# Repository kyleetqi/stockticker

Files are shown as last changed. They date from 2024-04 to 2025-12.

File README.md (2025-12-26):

# Introduction
* This project was inspired by Michael Klements' [ESP32 Stock Ticker](https://www.the-diy-life.com/bitcoin-ticker-using-an-esp32-and-oled-display/) and [this Reddit post.](https://www.reddit.com/r/wallstreetbets/comments/lfkprt/finished_my_diy_project_just_in_time_for_gme_to/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)
* These files are for **PERSONAL USE** only. Please contact me if you wish to use these files commercially.
* Please read through all documentation before starting this project.
* [Demo Video](https://youtu.be/1aN1ztKmoxc)

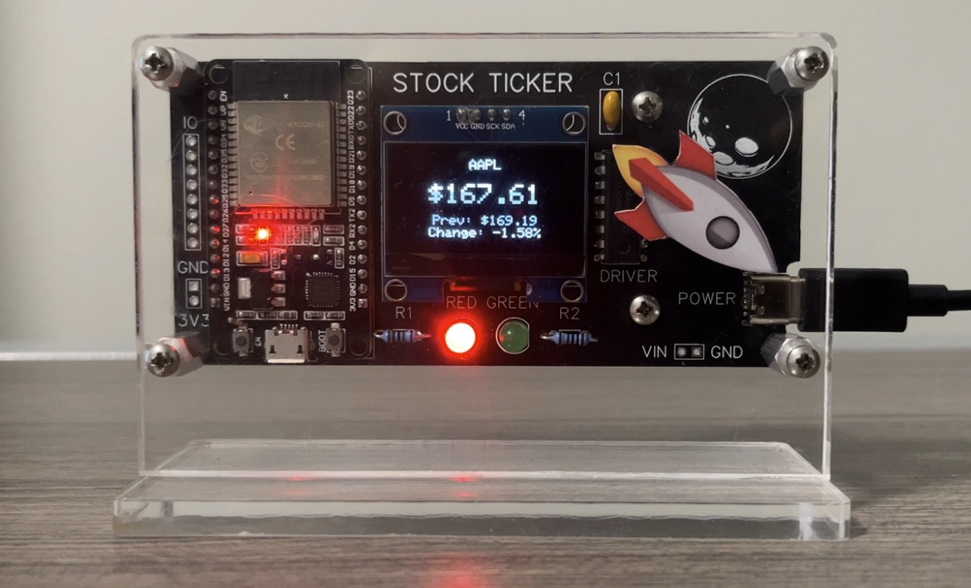
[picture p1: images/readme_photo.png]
Stock ticker display mounted on a circuit board.


# Known Issues and Limitations
* Although finnhub.io claims to provide live stock information, the API response may not be up to date at all times.
* Please contact me if you find any issues with the repository. :)
* There are some known issues with the USB-C port. 
  * Please check that your cable and brick can successfully supply power to the board. I had issues with Apple products.
  * The USB-C port is located a bit far into the board. Because of this, it may be necessary to file down the side of the PCB to plug in the cable. **PLEASE THOROUGHLY VERIFY IF THIS IS NECESSARY FOR YOU.**
* Because this project uses a stepper without absolute encoding, the ticker has no memory of the motor position between power ons. The pointer position needs to be reset before each power on.
  
# Bill of Materials
* I sourced all my parts from Sayal, (a hobbyist electronics store), but feel free to source from wherever you'd like.
* Use your judgement when substituting parts ensuring compatibility with the code and PCB. Modify the code and gerber as necessary.

### Required Items
Qty | Item Description | Notes |
--- | --- | --- |
1 | [DOIT ESP32 DEVKIT V1](https://shop.sayal.com/products/1815-ha1?_pos=1&_sid=3067e8a6e&_ss=r)  |  |
1 | [ULN2003 IC](https://shop.sayal.com/products/1814-lc1?_pos=3&_sid=53d498842&_ss=r) | The IC and motor come as a set if ordering from Sayal. | 
1 | [28BYJ-48 Stepper Motor](https://shop.sayal.com/products/1814-lc1?_pos=3&_sid=53d498842&_ss=r) | See note above. |
1 | [SH1106 OLED Display](https://shop.sayal.com/products/1814-fa1?_pos=1&_sid=ff4679778&_ss=r) | Some displays swap the position of VCC and GND. Verify the display pinout is compatible with PCB.|
1 | Red LED |  |
1 | Green LED |  |
1 | 0.1 uF capacitor | 1 uF should be fine as well. |
2 | Resistor | Choose between 360Ω and 1k Ω to control LED brightness. |
1 | [6-pin USB-C jack](https://shop.sayal.com/products/amtc-1154?_pos=3&_sid=0e93b7e13&_ss=r) |  |
1 | Pointer | 3D print using `pointer-rocket.stp`. If designing your own pointer, ensure the cylinder's inner diameter is 5mm. |
2 | #4-40 x 1/4" Screw | Used to mount the motor. M3 hardware is a suitable substitute. |
2 | #4-40 Nut | Used to mount the motor. M3 hardware is a suitable substitute. |
As Req. | Insulating tape | Electrical tape, etc. |

### Optional Items
* The following items are used to mount the PCB to the acrylic stand I designed. If you decide to mount the PCB another way, choose your hardware accordingly.

Qty | Item Description | Notes |
--- | --- | --- |
1 | Acrylic Stand | Laser cut using `pcb-cover.dwg` |
4 | [#4-40 x 12.7mm Standoff](https://shop.sayal.com/products/krc-164-2?_pos=8&_sid=6d0b828ae&_ss=r)| M3 hardware is a suitable substitute. |
4 | #4-40 x 1/4" Screw | M3 hardware is a suitable substitute. |
4 | #4-40 x 3/8" Screw | M3 hardware is a suitable substitute. |

# PCB
* If you plan on ordering PCBs using the provided gerber file, I recommend specifying where the manufacturer prints their PCB ID#. Make sure to select the `specify ID location` option before checking out!
  * If you are ordering from JLCPCB, you do not need to edit the gerber file.
  * If you are ordering from PCBWay, edit `JLCJLCJLCJLC` to `WayWayWay`.
  * If you are ordering from another manufacturer, follow their instructions accordingly.

# Software
* Ensure you have the Arduino IDE installed.
  * You may also use the PlatformIO extension on VSCode at your own discretion. 
* If this is your first time flashing your ESP32, I recommend referencing a [comprehensive setup guide.](https://randomnerdtutorials.com/installing-the-esp32-board-in-arduino-ide-windows-instructions/)
* Connect your ESP32 to your computer and open up `stockticker-public.ino` using the Arduino IDE.
* Ensure you have selected `DOIT ESP32 DEVKIT V1` as your board, and the correct serial port for communication.
  * At this stage, you may want to test if you have successfully established a connection with your ESP32. Try running an example such as the one at `File` > `Examples` > `Wifi` > `WiFiScan`
  * When trying to upload code onto your ESP32, you may encounter the error: `Failed to establish serial connection.` To resolve this, open the **serial monitor** and hold the `BOOT` and then `EN`(RESET) buttons down on your ESP32. You should see a response in the monitor at which point the code should be able to upload successfully.
* Install the following libraries required to compile the code:

Library Name | Author |
--- | --- |
Adafruit BusIO | Adafruit |
Adafruit GFX Library | Adafruit |
Adafruit SH110X | Adafruit | 
ArduinoJson | Benoit Blanchon |

* To fetch real, live stock market information, obtain a free API key from [finnhub.io.](https://finnhub.io/)
* Change the network and API parameters at the top of the code as necessary such as `symbol`, `key`, `ssid`, `pass`, etc.
* Modify the `updateTime` variable to set how frequently the device updates price information.
* Modify the `motorResponse` variable to control how sensitive the pointer is to stock changes.
* Verify and upload the code onto the ESP32.

# Soldering and Installation
* Before soldering components onto the board, use the schematic to wire and test the system on a breadboard to ensure everything is working.
* Verify that your cable can successfully plug into the USB-C port before soldering it into the board. See the `Known Issues and Limitations` section.
* Extract the ULN2003 IC from the driver board that comes with the motor and solder it directly onto the front of the PCB **before** installing the motor.
* [Insulate](./images/insulation-example.JPG) the ULN2003 pins on the backside of the PCB using the insulating tape.
* Mount the motor to the back of the PCB using hardware so that the shaft protrudes through the 10mm hole in the PCB towards the front.
* Cut the motor wires to length and solder them onto the back of the PCB making sure to pay attention to which color corresponds to which hole.
* Turn the PCB back over to the front and insulate the solder from the motor connections. Afterwards, solder on the OLED display.
* Solder all other components.
* Install the pointer onto the shaft of the motor.
* Mount the device using the fastener holes on the PCB.

# Operation
* Plug and play. Use power supply that is rated at 5V and can supply at least 2A. A phone charging brick should be sufficient. **DO NOT USE MORE THAN ONE POWER SOURCE AT THE SAME TIME.**
* Manually level the pointer to horizontal before powering the device since the motor does not have absolute encoding. The motor doesn’t remember its position between power ons.
* If the ESP32 is unable to establish a connection to the internet or API, it will automatically enter demo mode and generate random data.

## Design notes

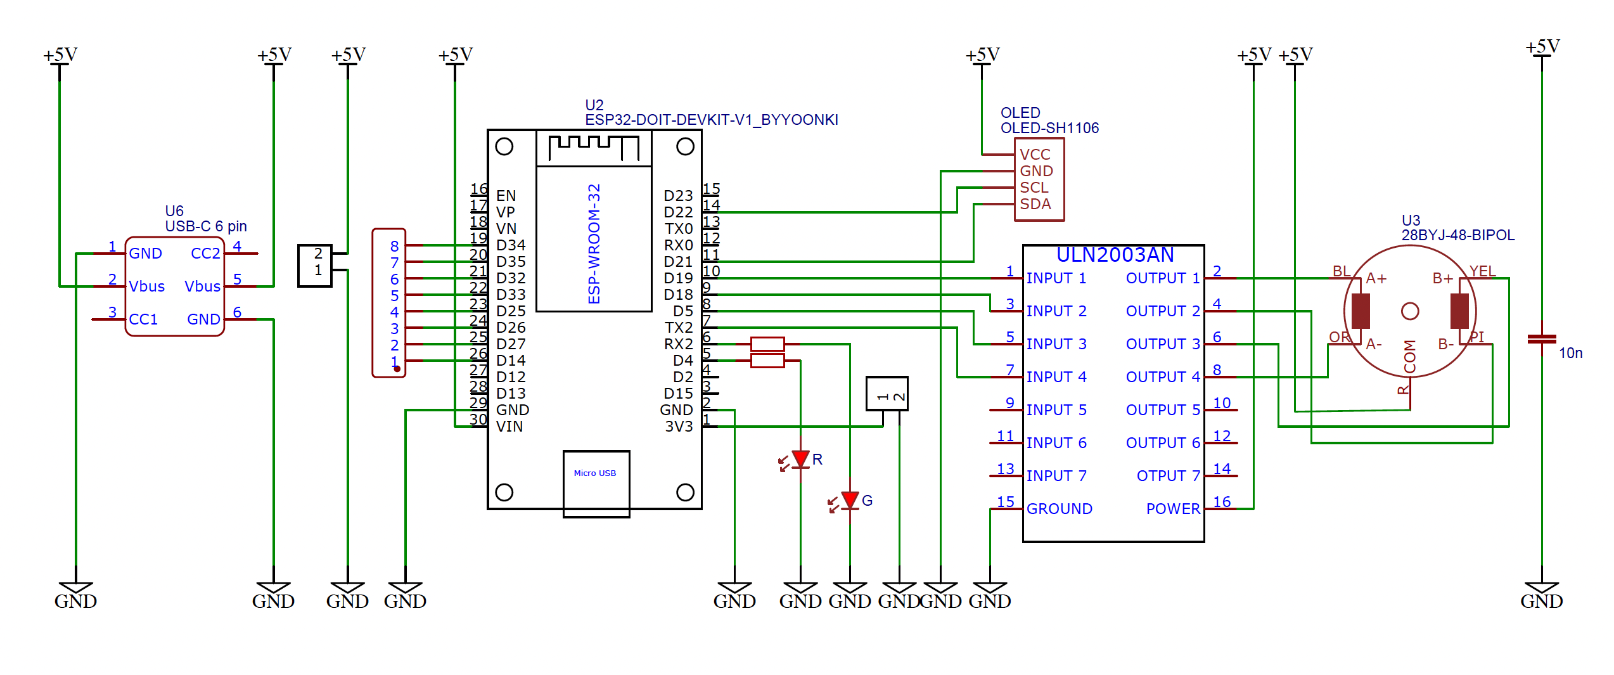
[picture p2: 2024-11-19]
schematic-11.18.24.png

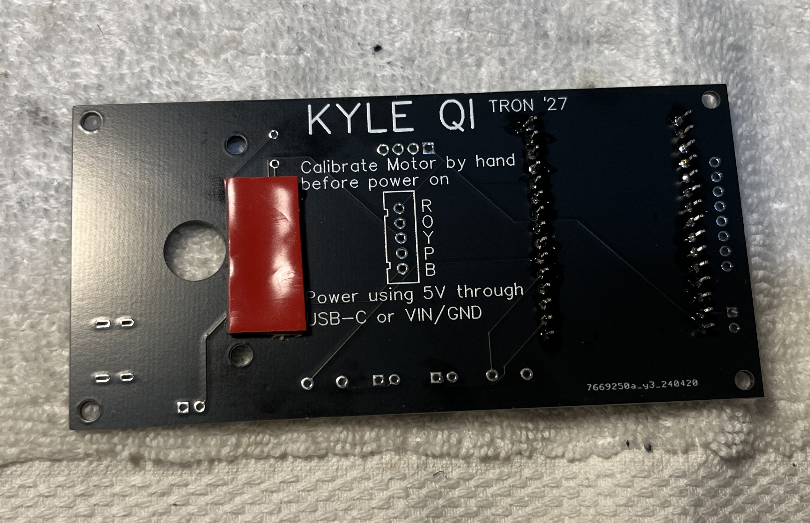
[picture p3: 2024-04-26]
images/insulation-example.JPG

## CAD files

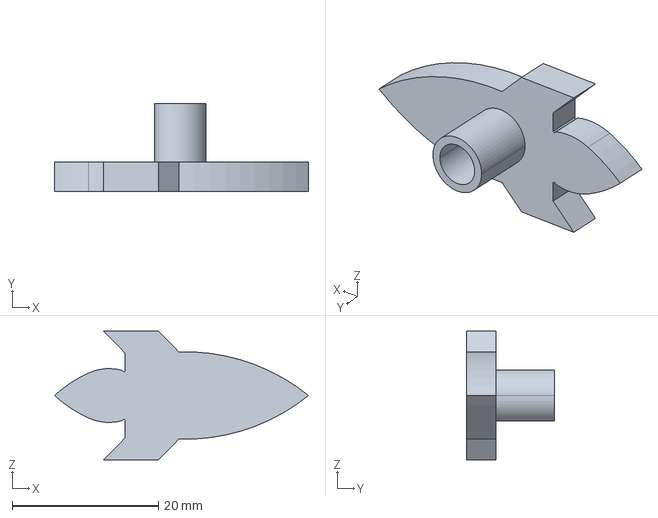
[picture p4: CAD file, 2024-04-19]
pointer-rocket.stp
34.7 x 12.0 x 17.6 mm

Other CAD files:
pcb-cover.dwg

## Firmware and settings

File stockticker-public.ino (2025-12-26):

// Including necessary libraries
#include <WiFi.h>
#include <HTTPClient.h>
#include <ArduinoJson.h>
#include <Wire.h>
#include <Adafruit_GFX.h>
#include <Adafruit_SH110X.h>
#include <Stepper.h>

// Declare OLED parameters
#define i2c_Address 0x3c
#define SCREEN_WIDTH 128
#define SCREEN_HEIGHT 64
#define OLED_RESET -1
Adafruit_SH1106G display = Adafruit_SH1106G(SCREEN_WIDTH, SCREEN_HEIGHT, &Wire, OLED_RESET);
bool isInverted = false;

// Declare stepper motor parameters
// The pinout order is kind of weird
// I discovered a wiring mistake so this is to compensate
#define IN1 19
#define IN2 17
#define IN3 18
#define IN4 5
const int stepsPerRev = 2048;
Stepper motor(stepsPerRev, IN1, IN3, IN2, IN4);
int currentPos = 0;
const int motorSpeed = 5;

// Controls how sensitive the motor is to stock changes.
// I recommend a value between 100 and 200.
// Pointer points vertically when % change equals 512/response.
// Ex: when response = 100, pointer becomes vertical at 512/100 = 5.12%.
const int motorResponse = 150;

// Declare LED parameters
const int pinRed = 4;
const int pinGreen = 16;

// Choose network information
const char* ssid ="yourNetworkName";
const char* pass = "yourNetworkPassword";
bool isOffline = false;

// Choose stock information
const String key = "yourAPIKey";
const String symbol = "yourSymbol";

// How often the ticker refreshes
// 10000 ms is good for demomode 
// but for practical purposes every few minutes is probably better
const int updateTime = 10000;

void setup(){
  Serial.begin(115200);
  setupLED();
  setupDisplay();
  setupMotor();
  setupWiFi();
}

void loop(){
  float differenceInPrice = 0.0;
  if (isOffline == true){
    differenceInPrice = demoMode();
  }
  else{
    differenceInPrice = checkPrice();
  }
  changeLED(differenceInPrice);
  currentPos = driveMotor(differenceInPrice);
  delay(updateTime);
}

// LED setup
void setupLED(){
  pinMode(pinRed, OUTPUT);
  pinMode(pinGreen, OUTPUT);
  digitalWrite(pinGreen, LOW);
  digitalWrite(pinRed, LOW);
}

// Changes LED colour
void changeLED(float diff){
  if(diff >= 0){
    digitalWrite(pinGreen, HIGH);
    digitalWrite(pinRed, LOW);
  }
  else{
    digitalWrite(pinRed, HIGH);
    digitalWrite(pinGreen, LOW);
  }
}

// Display setuo
void setupDisplay(){
  delay(250);
  display.setTextColor(SH110X_WHITE);
  display.begin(i2c_Address, true);
  display.setContrast(0); 
  display.display();
  delay(2000);
  display.clearDisplay();
}

// Displays text on LCD
void displayText(int col, int row, String text, int size){
  display.setTextSize(size);
  display.setCursor(col, row);
  display.println(text);
  display.display();
}

// Displays stock information
void displayPrice(float current, float previous, float change){
  display.clearDisplay();
  String currentText = "$" + String(current);
  String previousText = "Prev: $" + String(previous);
  String changeText = "Change: " + String(change) + "%";
  printCenter(symbol, 0, 4, 1);
  printCenter(currentText, 0, 22, 2);
  printCenter(previousText, 0, 45, 1);
  printCenter(changeText, 0, 54, 1);
}

// Inverts the display
void invertDisplay(){
  if (isInverted == false){
    display.invertDisplay(true);
    isInverted = true;
    return;
  }
  display.invertDisplay(false);
  isInverted = false;
  return;
}

// Center text on the OLED
void printCenter(const String buf, int x, int y, int size){
  int16_t x1, y1;
  uint16_t w, h;
  display.setTextSize(size);
  display.getTextBounds(buf, x, y, &x1, &y1, &w, &h);                     
  display.setCursor((x - w / 2) + (128 / 2), y);                          
  display.print(buf);
  display.display();                                                     
}

// Fetches stock info
// and returns differenceInPrice for the motor and LED
float checkPrice(){
  HTTPClient http;
  int httpCode;
  http.begin("https://finnhub.io/api/v1/quote?symbol=" + symbol + "&token=" + key);
  httpCode = http.GET();

  float differenceInPrice = 0;

  if(httpCode > 0){
    DynamicJsonDocument doc(1024);
    String payload = http.getString();
    // Serial.println(payload);
    deserializeJson(doc, payload);

    float previousClosePrice = doc["pc"];
    float currentPrice = doc["c"];
    if (currentPrice == 0){
      display.clearDisplay();
      displayText(0, 0, "No Available Info!", 1);
      displayText(0, 8, "Entering Demo Mode.", 1);
      isOffline = true;
      delay(3000);
      http.end();
      return 0;
    }
    differenceInPrice = ((currentPrice-previousClosePrice)/previousClosePrice)*100.0;
    displayPrice(currentPrice, previousClosePrice, differenceInPrice);
  } 
  else{
    display.clearDisplay();
    displayText(0, 0, "HTTP Req. Error!", 1);
    displayText(0, 8, "Entering Demo Mode.", 1);
    isOffline = true;
  }
  http.end();
  return differenceInPrice;
}

// Set up WiFi
void setupWiFi(){
  WiFi.mode(WIFI_STA);
  WiFi.disconnect();
  WiFi.begin(ssid, pass);
  displayText(0, 0, "Connecting to WiFi", 1);
  delay(1000);
  int i = 0;
  while (WiFi.status() != WL_CONNECTED){
    displayText(2*i, 10, ".", 1);
    i++;
    delay(1000);
    if (i == 10){
      isOffline = true;
      break;
    }
  } 
  display.clearDisplay();
  if (isOffline == false){
    displayText(0, 0, "Connection Success!", 1);
  }
  else{
    displayText(0, 0, "Connection Failed!", 1);
    displayText(0, 8, "Entering Demo Mode.", 1);
  }
  delay(3000);
}

// Setup motor
void setupMotor(){
  motor.setSpeed(motorSpeed);
  digitalWrite(IN1, LOW);
  digitalWrite(IN2, LOW);
  digitalWrite(IN3, LOW);
  digitalWrite(IN4, LOW);
}

// Sets the motor output pins to high low
// Function used to conserve power
// 1 -> on, 0 -> off
void motorPower(bool onoff){
  if (onoff == true){
    digitalWrite(IN1, HIGH);
    digitalWrite(IN2, HIGH);
    digitalWrite(IN3, HIGH);
    digitalWrite(IN4, HIGH);
    return;
  }
  digitalWrite(IN1, LOW);
  digitalWrite(IN2, LOW);
  digitalWrite(IN3, LOW);
  digitalWrite(IN4, LOW);
  return;
}

// Positions the motor based on % change
// Returns # of steps to track relative position
int driveMotor(float diff){
  motorPower(true);
  invertDisplay();
  int targetPos = round(diff*motorResponse);
  if (diff > 512/motorResponse)
  {
    targetPos = 512;
  } 
  else if (diff < -512/motorResponse)
  {
    targetPos = -512;
  }
  motor.step(targetPos - currentPos);
  motorPower(false);
  invertDisplay();
  return targetPos;
}

// Generating information if API is unreachable
float demoMode(){
  float randomDiff = random(-256, 256);
  randomDiff = randomDiff/100.0;
  displayPrice(randomDiff + 100.00, 100.00, randomDiff);
  return randomDiff;
}

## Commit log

2024-04-19 Add gerber and schematic via file upload
2024-04-19 Add pointer via file upload
    [pointer-rocket.stp]
2024-04-22 Add Gerber via file upload
2024-04-23 Add schematic via file upload
2024-04-25 Update stockticker-public.ino
    Change pinout order for motor to compensate for wiring issue
    [stockticker-public.ino]
